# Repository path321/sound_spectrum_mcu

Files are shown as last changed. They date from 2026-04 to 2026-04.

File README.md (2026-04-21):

# Sound Analyzer

STM32-powered board for analyzing sound input from MEMS microphones, designed as an open-source, hands-on introduction to DSP on ARM Cortex-M4 processors.

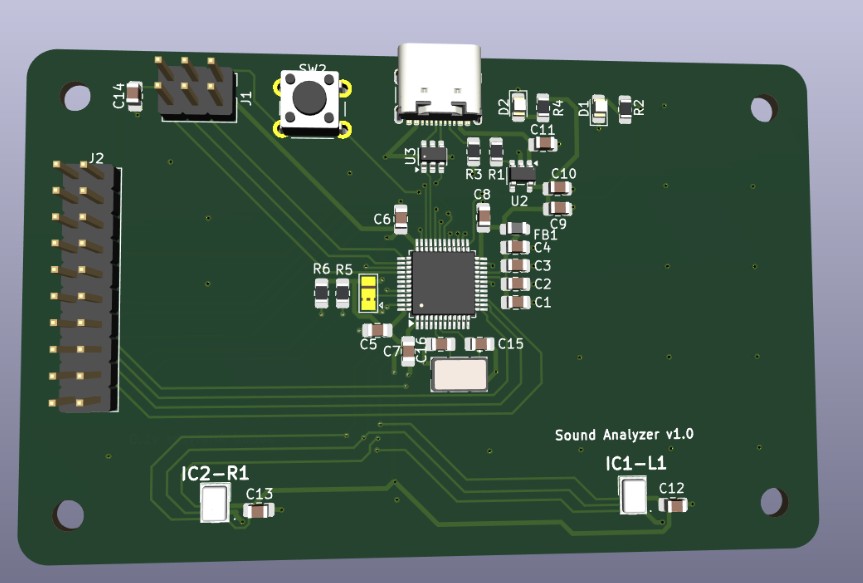
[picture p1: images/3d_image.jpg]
device_image


## Table of Contents

1. [About the Project](#about-the-project)
1. [Project Status](#project-status)
1. [Getting Started](#getting-started)
	1. [Getting the Source](#getting-the-source)
	1. [Usage](#usage)
	1. [Versioning](#versioning)
1. [How to get help](#how-to-get-help)
1. [License](#license)

## About the Project

It uses the CMSIS-DSP library to handle computationally intensive tasks, while a companion PyQt-based Python script is used for plotting frequency-domain data data from PCB to host PC. 

The goal is to demonstrate the full pipeline of audio signal acquisition and transformation, from raw time-domain data to frequency-domain analysis

The PCB intentionally exposes additional unused pins, allowing users to extend functionality and experiment beyond the core features

_1kHz sine_
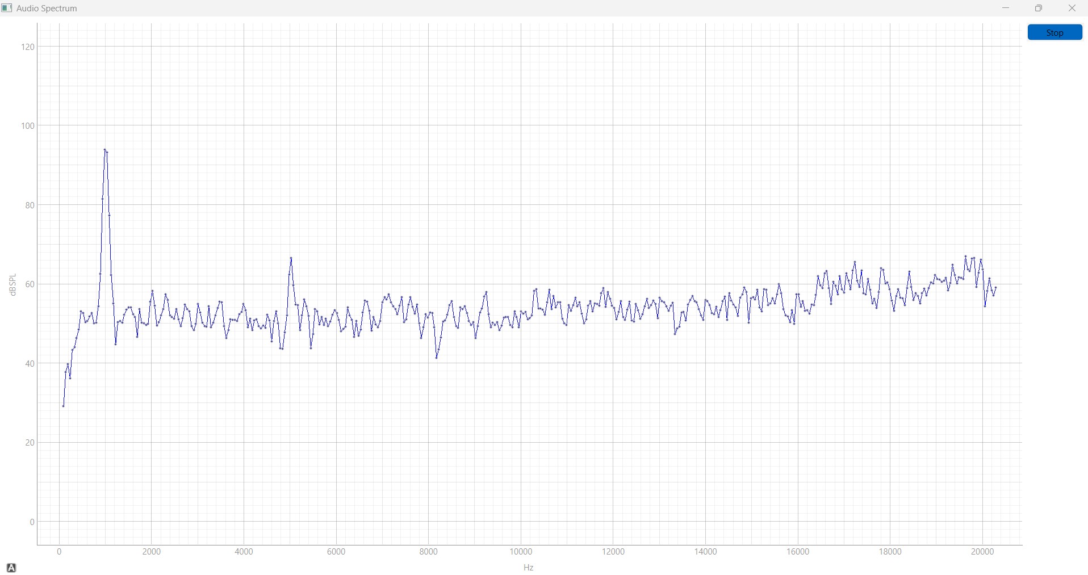
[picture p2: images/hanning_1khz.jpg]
1khz


Front                      |  Back
:-------------------------:|:-------------------------:
device_image  |  device_image

**[Back to top](#table-of-contents)**

## Project Status

In progress, working version availabe in `main` branch

Full STM32CubeIDE project is hosted here, with .elf and .bin files ready inside `code/sound_analyzer_v1/Debug` folder

As for python script, both source `plot_graph.py` and executable `plot_graph.exe` are available, with executable tested only for Windows platform

**[Back to top](#table-of-contents)**

## Getting Started

For application usage, no extra programm shall be installed , other than downloading the executable plot_graph.exe

For developer usage, STM32CubeIDE + STM32CubeMX shall be installed, as described [here](https://wiki.st.com/stm32mcu/wiki/STM32StepByStep:Step1_Tools_installation)

In addition, Python >=3.9 shall be installed from [here](https://www.python.org/downloads/), with the following Python libraries also installed :
- Numpy
- PySide6
- pyqtgraph
- Pyserial

PCB files are located on `pcb/` folder, while device files can be found on `code/sound_analyzer_v1/` and plot files on `code/plot_graph/`

### Getting the Source

This project is [hosted on GitHub](https://github.com/path321/sound_spectrum_mcu). You can clone this project directly using this command:

```
https://github.com/path321/sound_spectrum_mcu.git
```

### Usage

1) Connect the board via USB to your host PC. Make sure that no other STM32-based USB is connected to PC

2) Unzip plot_graph.zip Double click on plot_graph.exe

3) If you want to stop the live graph, check on the Button on the top right end of the GUI window

### Versioning

This project uses [Semantic Versioning](http://semver.org/). For a list of available versions, see the [repository tag list](https://github.com/path321/sound_spectrum_mcu/tags).

**[Back to top](#table-of-contents)**

## How to Get Help

Please create a new issue on

```https://github.com/path321/sound_spectrum_mcu/issues```

**[Back to top](#table-of-contents)**

## License

This project is licensed under the MIT License - see [LICENSE.md](LICENSE.md) file for details.

**[Back to top](#table-of-contents)**

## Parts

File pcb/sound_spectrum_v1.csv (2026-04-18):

Reference | Qty | Value | DNP | Exclude from BOM | Exclude from Board | Footprint | Datasheet | Manufacturer_Part_Number
C1,C3,C6,C7,C8,C12,C13,C14 | 8 | 100nF |  |  |  | Capacitor_SMD:C_0805_2012Metric_Pad1.18x1.45mm_HandSolder | ~ | 581-KGM21NR71E104KM
C2,C4,C5,C9 | 4 | 1uF |  |  |  | Capacitor_SMD:C_0805_2012Metric_Pad1.18x1.45mm_HandSolder | ~ | 80-C0805C105Z4VAC
C10,C11 | 2 | 10uF |  |  |  | Capacitor_SMD:C_0805_2012Metric_Pad1.18x1.45mm_HandSolder | ~ | 81-GRM21BR61C106KE15
C15,C16 | 2 | 33pF |  |  |  | Capacitor_SMD:C_0805_2012Metric_Pad1.18x1.45mm_HandSolder | ~ | 80-C0805C105Z4VAC
D1 | 1 | LED - Green |  |  |  | LED_SMD:LED_0805_2012Metric_Pad1.15x1.40mm_HandSolder | ~ | C171KGKT
D2 | 1 | LED - Red |  |  |  | LED_SMD:LED_0805_2012Metric_Pad1.15x1.40mm_HandSolder | ~ | CMDA5AR7D1S
FB1 | 1 | ~ |  |  |  | Inductor_SMD:L_0805_2012Metric_Pad1.05x1.20mm_HandSolder | ~ | ASMPH-0805-4R7M-T
IC1-L1,IC2-R1 | 2 | ICS-43432 |  |  |  | ICS43432 | https://product.tdk.com/system/files/dam/doc/product/sw_piezo/mic/mems-mic/data_sheet/ics-43432-data-sheet-v1.3.pdf | ICS-43432
J1 | 1 | SWD_CONN |  |  |  | Connector_PinHeader_2.54mm:PinHeader_2x03_P2.54mm_Vertical | ~ | 10129381-906004BLF
J2 | 1 | Conn_02x10_Counter_Clockwise |  |  |  | Connector_PinHeader_2.54mm:PinHeader_2x10_P2.54mm_Vertical | ~ | 77313-818-20LF
P1 | 1 | USB_C_Plug_USB2.0 |  |  |  | Connector_USB:USB_C_Receptacle_GCT_USB4105-xx-A_16P_TopMnt_Horizontal | https://www.usb.org/sites/default/files/documents/usb_type-c.zip | USB4085-GF-A
R1 | 1 | 10k |  |  |  | Resistor_SMD:R_0805_2012Metric_Pad1.20x1.40mm_HandSolder | ~ | 603-AC0805DR-0710KL
R2,R4 | 2 | 1k |  |  |  | Resistor_SMD:R_0805_2012Metric_Pad1.20x1.40mm_HandSolder | ~ | 603-AA0805FR-071KL
R3 | 1 | 5.1k |  |  |  | Resistor_SMD:R_0805_2012Metric_Pad1.20x1.40mm_HandSolder | ~ | CRCW08055K10JNEA
R5,R6 | 2 | 4.7k |  |  |  | Resistor_SMD:R_0805_2012Metric_Pad1.20x1.40mm_HandSolder | ~ | 603-RC0805FR-074K7L
SW2 | 1 | SW_DPST_x2 |  |  |  | Button_Switch_THT:SW_PUSH_6mm | ~ | TS04-66-55-BK-100-SMT-TR
U1 | 1 | STM32G473CBTx |  |  |  | Package_QFP:LQFP-48_7x7mm_P0.5mm | https://www.st.com/resource/en/datasheet/stm32g473cb.pdf | STM32G473CBT6
U2 | 1 | AP2112K-3.3 |  |  |  | Package_TO_SOT_SMD:SOT-23-5 | https://www.diodes.com/assets/Datasheets/AP2112.pdf | AP2112K-3.3TRG1
U3 | 1 | USBLC6-2SC6 |  |  |  | Package_TO_SOT_SMD:SOT-23-6 | https://www.st.com/resource/en/datasheet/usblc6-2.pdf | USBLC6-2SC6
Y1 | 1 | ABMM2-24.000MHZ-E2-T |  |  |  | ABMM2 | https://abracon.com/Resonators/ABMM2.pdf | ABMM2-24.000MHZ-E2-T

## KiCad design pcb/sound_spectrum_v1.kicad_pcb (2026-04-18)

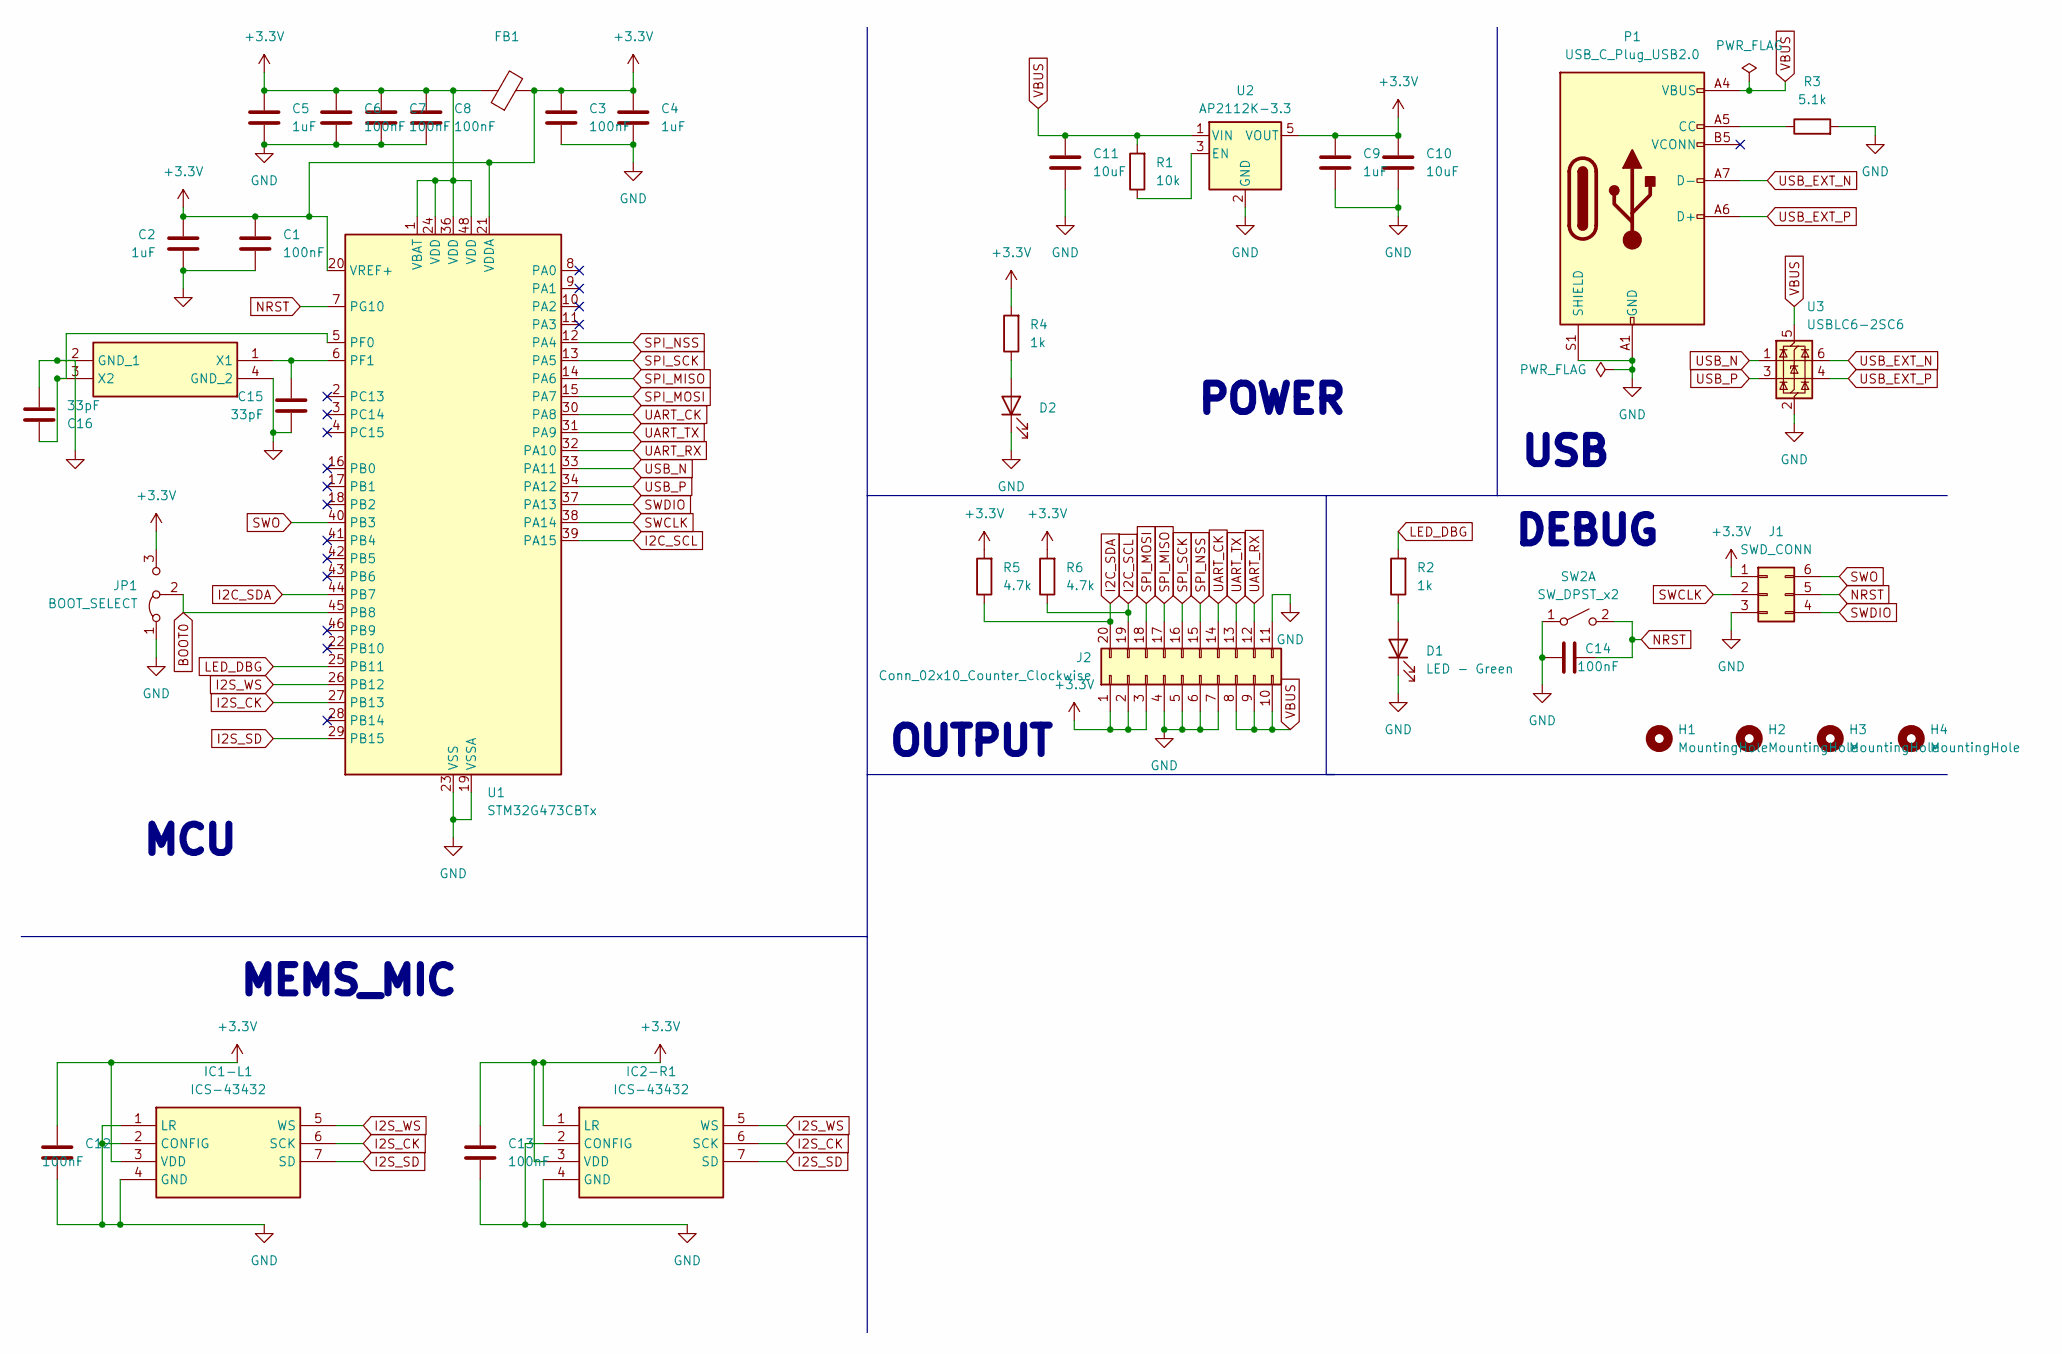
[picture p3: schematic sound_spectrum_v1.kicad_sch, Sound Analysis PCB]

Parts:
C1, C3, C6, C7, C8, C12, C13, C14: 100nF; C_0805_2012Metric_Pad1.18x1.45mm_HandSolder; Manufacturer_Part_Number 581-KGM21NR71E104KM
C2, C4, C5, C9: 1uF; C_0805_2012Metric_Pad1.18x1.45mm_HandSolder; Manufacturer_Part_Number 80-C0805C105Z4VAC
C10, C11: 10uF; C_0805_2012Metric_Pad1.18x1.45mm_HandSolder; Manufacturer_Part_Number 81-GRM21BR61C106KE15
C15, C16: 33pF; C_0805_2012Metric_Pad1.18x1.45mm_HandSolder; Manufacturer_Part_Number 80-C0805C105Z4VAC
D1: LED - Green; LED_0805_2012Metric_Pad1.15x1.40mm_HandSolder; Manufacturer_Part_Number C171KGKT
D2: LED - Red; LED_0805_2012Metric_Pad1.15x1.40mm_HandSolder; Manufacturer_Part_Number CMDA5AR7D1S
FB1: L_0805_2012Metric_Pad1.05x1.20mm_HandSolder; Manufacturer_Part_Number ASMPH-0805-4R7M-T
H1, H2, H3, H4: MountingHole; MountingHole_3.2mm_M3_DIN965
IC1-L1, IC2-R1: ICS-43432; ICS43432; Manufacturer_Part_Number ICS-43432; Mouser Part Number 410-ICS-43432
J1: SWD_CONN; PinHeader_2x03_P2.54mm_Vertical; Manufacturer_Part_Number 10129381-906004BLF
J2: Conn_02x10_Counter_Clockwise; PinHeader_2x10_P2.54mm_Vertical; Manufacturer_Part_Number 77313-818-20LF
JP1: BOOT_SELECT; SolderJumper-3_P1.3mm_Bridged2Bar12_Pad1.0x1.5mm
P1: USB_C_Plug_USB2.0; USB_C_Receptacle_GCT_USB4105-xx-A_16P_TopMnt_Horizontal; Manufacturer_Part_Number USB4085-GF-A
R1: 10k; R_0805_2012Metric_Pad1.20x1.40mm_HandSolder; Manufacturer_Part_Number 603-AC0805DR-0710KL
R2, R4: 1k; R_0805_2012Metric_Pad1.20x1.40mm_HandSolder; Manufacturer_Part_Number 603-AA0805FR-071KL
R3: 5.1k; R_0805_2012Metric_Pad1.20x1.40mm_HandSolder; Manufacturer_Part_Number CRCW08055K10JNEA
R5, R6: 4.7k; R_0805_2012Metric_Pad1.20x1.40mm_HandSolder; Manufacturer_Part_Number 603-RC0805FR-074K7L
SW2: SW_DPST_x2; SW_PUSH_6mm; Manufacturer_Part_Number TS04-66-55-BK-100-SMT-TR
U1: STM32G473CBTx; LQFP-48_7x7mm_P0.5mm; Manufacturer_Part_Number STM32G473CBT6
U2: AP2112K-3.3; SOT-23-5; Manufacturer_Part_Number AP2112K-3.3TRG1
U3: USBLC6-2SC6; SOT-23-6; Manufacturer_Part_Number USBLC6-2SC6
Y1: ABMM2-24.000MHZ-E2-T; ABMM2; Mouser Part Number 815-ABMM2-24-E2T

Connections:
+3.3V: C1.1, C2.1, C3.1, C4.1, C5.1, C6.1, C7.1, C8.1, C9.1, C10.1, C12.1, C13.1, FB1.1, FB1.2, IC1-L1.3 (VDD), IC2-R1.1 (LR), IC2-R1.3 (VDD), J1.1, J2.1, J2.2, J2.3, JP1.3 (B), R4.2, R5.2, R6.2, U1.1 (VBAT), U1.20 (VREF+), U1.21 (VDDA), U1.24 (VDD), U1.36 (VDD), U1.48 (VDD), U2.5 (VOUT)
BOOT0: JP1.2 (C), U1.45 (PB8)
GND: C1.2, C2.2, C3.2, C4.2, C5.2, C6.2, C7.2, C8.2, C9.2, C10.2, C11.2, C12.2, C13.2, C14.1, C15.2, C16.2, D1.1 (K), D2.1 (K), IC1-L1.1 (LR), IC1-L1.2 (CONFIG), IC1-L1.4 (GND), IC2-R1.2 (CONFIG), IC2-R1.4 (GND), J1.3, J2.4, J2.5, J2.6, J2.7, J2.11, JP1.1 (A), P1.A1 (GND), P1.A12 (GND), P1.B1 (GND), P1.B12 (GND), P1.S1 (SHIELD), R3.2, SW2.1 (A), U1.19 (VSSA), U1.23 (VSS), U1.35 (VSS), U1.47 (VSS), U2.2 (GND), U3.2 (GND), Y1.2 (GND_1), Y1.4 (GND_2)
I2C_SCL: J2.19, R6.1, U1.39 (PA15)
I2C_SDA: J2.20, R5.1, U1.44 (PB7)
I2S_CK: IC1-L1.6 (SCK), IC2-R1.6 (SCK), U1.27 (PB13)
I2S_SD: IC1-L1.7 (SD), IC2-R1.7 (SD), U1.29 (PB15)
I2S_WS: IC1-L1.5 (WS), IC2-R1.5 (WS), U1.26 (PB12)
LED_DBG: R2.2, U1.25 (PB11)
NRST: C14.2, J1.5, SW2.2 (B), U1.7 (PG10)
unnamed: D1.2 (A), R2.1
unnamed: D2.2 (A), R4.1
unnamed: P1.A5 (CC), R3.1
unnamed: C16.1, U1.5 (PF0), Y1.3 (X2)
unnamed: C15.1, U1.6 (PF1), Y1.1 (X1)
unnamed: R1.1, U2.3 (EN)
SPI_MISO: J2.17, U1.14 (PA6)
SPI_MOSI: J2.18, U1.15 (PA7)
SPI_NSS: J2.15, U1.12 (PA4)
SPI_SCK: J2.16, U1.13 (PA5)
SWCLK: J1.2, U1.38 (PA14)
SWDIO: J1.4, U1.37 (PA13)
SWO: J1.6, U1.40 (PB3)
UART_CK: J2.14, U1.30 (PA8)
UART_RX: J2.12, U1.32 (PA10)
UART_TX: J2.13, U1.31 (PA9)
USB_EXT_N: P1.A7 (D-), U3.6 (I/O1)
USB_EXT_P: P1.A6 (D+), U3.4 (I/O2)
USB_N: U1.33 (PA11), U3.1 (I/O1)
USB_P: U1.34 (PA12), U3.3 (I/O2)
VBUS: C11.1, J2.8, J2.9, J2.10, P1.A4 (VBUS), P1.A9 (VBUS), P1.B4 (VBUS), P1.B9 (VBUS), R1.2, U2.1 (VIN), U3.5 (VBUS)

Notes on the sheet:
MEMS_MIC
DEBUG
OUTPUT
MCU
USB
POWER

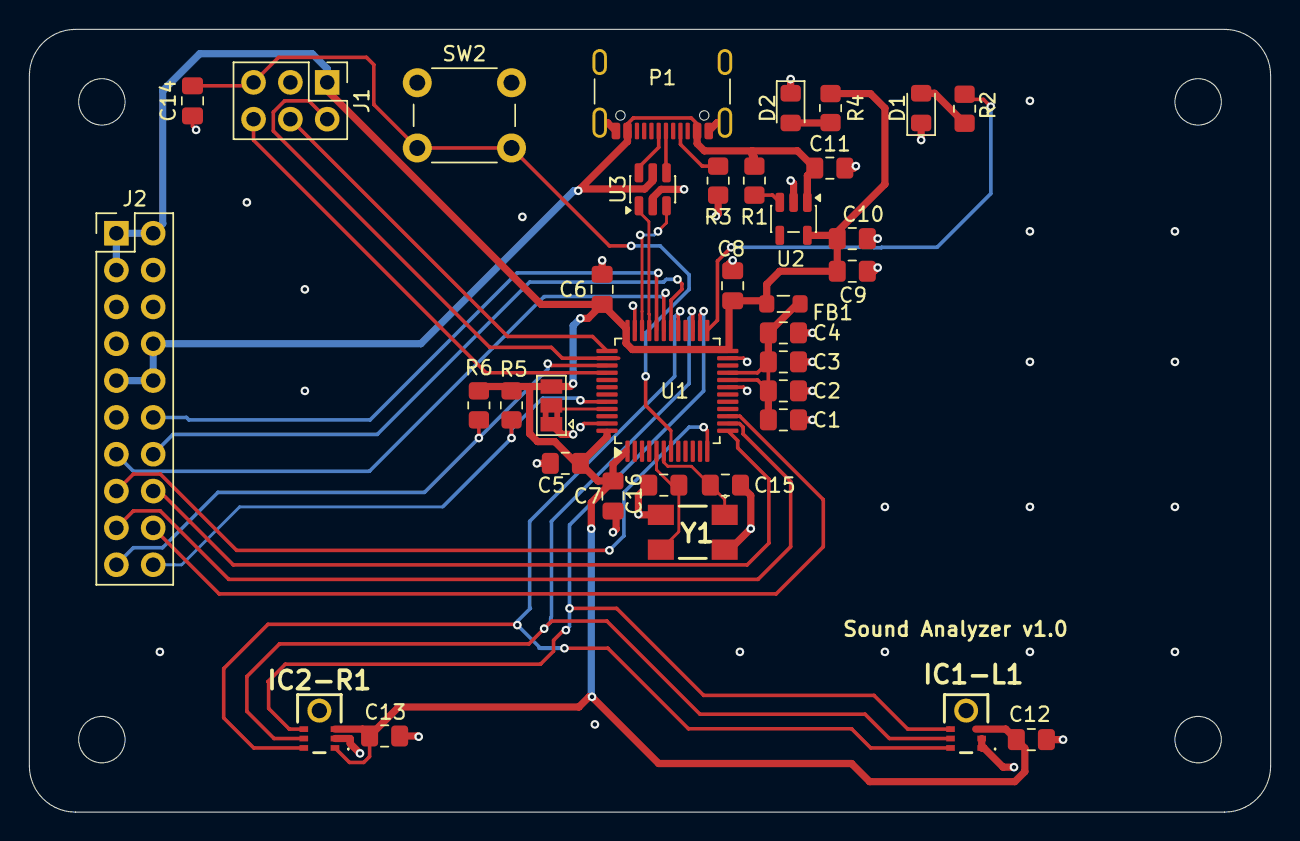
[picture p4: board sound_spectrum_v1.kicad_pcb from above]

Board: 4 copper layers, 85.6 x 54.0 mm, 40 parts (0 on the bottom side), 31 nets.

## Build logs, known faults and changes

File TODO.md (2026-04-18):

# TODO
Check the following in order to keep track of tasks

## Device FW & HW
  - [ ] Optimize USB transmit
  - [ ] Measure duration of each process
  - [ ] Display Average value

## PC SW (plotting)
 - [ ] Use Bar graphs instead of lines

## Backlog
- [ ] Redesign USB lines, as they are unstable
- [ ] Detect L/R orientation of larger frequency
- [ ] Add 'checksum' in frame / Ensure frame integrity

## Notes for next version
- Redesign USB lines, as they are unstable
- Add audio codec IC
- Use larger resistor for Green Led (too bright now)
- Use MCU with larger Flash

## Done
- [x] Demo firmware on STM32401RE-NUCLEO + ICS43434 board
- [x] Design HW board for STM32G473CBT
- [x] Plot data with Python real time-like
- [x] Show only >50Hz and <20.3kHz in X-axis
- [x] Average signal between transmit
- [X] Show error message in case device is not found
- [X] Add buttons for Run/Stop plotting
- [X] Code restructure with PySide
- [X] Detect COM port of HW board automatically via USB descriptors (need improving)

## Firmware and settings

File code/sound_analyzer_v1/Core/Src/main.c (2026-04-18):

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
/* Includes ------------------------------------------------------------------*/
#include "main.h"
#include "usb_device.h"

/* USER CODE BEGIN Includes */
#include "usbd_cdc_if.h"
#include <string.h>
#include <stdbool.h>
#include "arm_math.h"
#include "weighting.h"
#include "window.h"
/* USER CODE END Includes */

/* USER CODE BEGIN PD */
#define ARM_MATH_CM4

#define DOUBLE_BUFFER_SIZE 4096
#define HALF_DOUBLE_BUFFER_SIZE DOUBLE_BUFFER_SIZE/2
#define FFT_SIZE 1024
#define HALF_FFT_SIZE FFT_SIZE/2
#define SAMPLING_RATE 47872//~48000 , taken from CubeMX

#define USE_FLATTOP_WINDOW
//#define USE_HANNING_WINDOW
//#define USE_RECTANGULAR_WINDOW

#define USE_A_WEIGHTING
//#define USE_C_WEIGHTING

#if ((!defined(USE_FLATTOP_WINDOW))&&(!defined(USE_HANNING_WINDOW))&&(!defined(USE_RECTANGULAR_WINDOW)) || (defined(USE_HANNING_WINDOW)&&defined(USE_RECTANGULAR_WINDOW))|| (defined(USE_FLATTOP_WINDOW)&&defined(USE_RECTANGULAR_WINDOW)) || (defined(USE_FLATTOP_WINDOW)&&defined(USE_HANNING_WINDOW)))
#error "Please choose at least one between GSM,NBIOT and CATM definition"
#endif

#if defined(USE_A_WEIGHTING) && defined(USE_C_WEIGHTING)
#error "Please choose only 1 between A and C weighting"
#endif

#if (DOUBLE_BUFFER_SIZE % FFT_SIZE) != 0
#error "Input buffer size shall be integer multiple of FFT size"
#endif
/* USER CODE END PD */

I2S_HandleTypeDef hi2s2;
DMA_HandleTypeDef hdma_spi2_rx;

/* USER CODE BEGIN PV */
static uint16_t mic_data[DOUBLE_BUFFER_SIZE];
static volatile uint16_t *buf_ptr = &mic_data[0]; //pointer to each half of buffer

static volatile bool data_ready_flag = false;
static volatile bool buffer_filled = false;
static volatile bool fft_done = false;
/* USER CODE END PV */

void SystemClock_Config(void);
static void MX_GPIO_Init(void);
static void MX_DMA_Init(void);
static void MX_I2S2_Init(void);
/* USER CODE BEGIN PFP */

static void process_input_data(float32_t*);
static void compute_frequencies(arm_rfft_fast_instance_f32*,float32_t*,float32_t*);
static void scale_frequencies(float32_t* , float32_t* );
static void show_values(float32_t*, size_t );
/* USER CODE END PFP */

/**
 * @brief  The application entry point.
 * @retval int
 */
int main(void) {

	/* MCU Configuration--------------------------------------------------------*/

	/* Reset of all peripherals, Initializes the Flash interface and the Systick. */
	HAL_Init();

	/* Configure the system clock */
	SystemClock_Config();

	/* USER CODE BEGIN SysInit */
#if 0
  //Enable cycle counter for measuring time duration
  CoreDebug->DEMCR |= CoreDebug_DEMCR_TRCENA_Msk;
  DWT->CYCCNT = 0;
  DWT->CTRL |= DWT_CTRL_CYCCNTENA_Msk;
  volatile uint32_t t1;
  volatile uint32_t t2;
  volatile uint32_t diff;
  const uint32_t sys_clock_freq = HAL_RCC_GetSysClockFreq();
#endif
	/* USER CODE END SysInit */

	/* Initialize all configured peripherals */
	MX_GPIO_Init();
	MX_DMA_Init();
	MX_I2S2_Init();
	MX_USB_Device_Init();
	/* USER CODE BEGIN 2 */
	arm_rfft_fast_instance_f32 hfft;
	//const float32_t frequency_resolution = (float32_t) SAMPLING_RATE / (float32_t) FFT_SIZE;

	float32_t input_td[FFT_SIZE] = { 0 };
	float32_t fft_mag[HALF_FFT_SIZE] = { 0 };
	float32_t output_db[HALF_FFT_SIZE] = { 0 };

	uint32_t last_send = 0;
	uint32_t refresh_time = 10; //ms

	HAL_GPIO_WritePin(LED_DBG_GPIO_Port, LED_DBG_Pin, GPIO_PIN_SET);
	HAL_Delay(500);
	HAL_GPIO_WritePin(LED_DBG_GPIO_Port, LED_DBG_Pin, GPIO_PIN_RESET);
	HAL_Delay(500);

	//arm_rfft_fast_init_f32(&hfft, FFT_SIZE);
#if (FFT_SIZE != 1024)
#error "Please use respective arm_rfft_fast_init_XXX_f32() function"
#else
	arm_rfft_fast_init_1024_f32(&hfft); //Use specific size for less build code size
#endif

	//Start reading from microphones
	if (HAL_I2S_Receive_DMA(&hi2s2, mic_data, HALF_DOUBLE_BUFFER_SIZE)
			!= HAL_OK) {
		Error_Handler();
	}

	//Successful initilization
	HAL_GPIO_WritePin(LED_DBG_GPIO_Port, LED_DBG_Pin, GPIO_PIN_SET);

	/* USER CODE END 2 */

	/* Infinite loop */
	/* USER CODE BEGIN WHILE */
	while (1) {
		if (data_ready_flag) {
			data_ready_flag = false;
			process_input_data(input_td);
		}

		if (buffer_filled) {
			buffer_filled = false;
			compute_frequencies(&hfft, input_td,fft_mag);
		}

		if (((HAL_GetTick() - last_send) >= refresh_time) && fft_done && tx_complete) {
			last_send = HAL_GetTick();
			fft_done = false;
			tx_complete = false;
			scale_frequencies(fft_mag, output_db);
			show_values(output_db, HALF_FFT_SIZE);
		}
		/* USER CODE END WHILE */

		/* USER CODE BEGIN 3 */
	}
	/* USER CODE END 3 */
}

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
/* USER CODE BEGIN 4 */
/**
 * @brief Reform incoming data from stereo 24-bit integer to mono float, to prepare them for FFT
 * param[out] input_td Array to store time-domain data from microphone
 */
static void process_input_data(float32_t* mic_data) {

	static int index = 0;
	uint16_t input_data[HALF_DOUBLE_BUFFER_SIZE];
	static const float32_t full_range = 0x7fffff; //2^23 - 1

	//Copy data to avoid corruption
	memcpy(input_data, (uint16_t*) buf_ptr, sizeof(input_data));

	for (size_t i = 0; i < HALF_DOUBLE_BUFFER_SIZE; i = i + 4) {
		// Get data from I2S for each channel
		int32_t left_channel = (((int32_t) input_data[i] << 16)
				| input_data[i + 1]);
		int32_t right_channel = (((int32_t) input_data[i + 2] << 16)
				| input_data[i + 3]);

		//Keep only 24bits and take care of sign
		left_channel &= 0xFFFFFF;
		right_channel &= 0xFFFFFF;
		if (left_channel & 0x800000) {
			left_channel |= ~0xFFFFFF;
		}
		if (right_channel & 0x800000) {
			right_channel |= ~0xFFFFFF;
		}

		//Stereo to mono ( (L+R)/2 ) & normalize to Full Scale [-1.0,1.0]
		float32_t mono = ((float32_t) (left_channel + right_channel) / 2.0)
				/ full_range;

		mic_data[index] = mono;
		index++;
	}

	if (index == FFT_SIZE) {
		buffer_filled = true;
		index = 0; // set for next iteration
	}

}

/**
 * @brief Apply Fast Fourier Transformation to incoming data and compute spectral content of signal
 * @param[in] hfft FFT handler
 * @param[in] input_td Time-domain data from microphone
 * @param[out] out_freq dBFS signal values in frequency
 */
static void compute_frequencies(arm_rfft_fast_instance_f32* hfft,float32_t* input_td,float32_t* output_freq) {

	//Intermediate buffers used as input/output between actions
	float32_t input_td_windowed[FFT_SIZE] = { 0 };
	float32_t fft_out[FFT_SIZE] = { 0 };
	float32_t mag_now[HALF_FFT_SIZE] = { 0 };
	float32_t temp[HALF_FFT_SIZE] = { 0 };
	static const uint8_t ifft_flag = 0;

	//Weight for current values in weighted moving average
	static const float32_t alpha = 0.5;

	//Window functions
#if defined(USE_HANNING_WINDOW)
	static float32_t const* window = hanning;
	static float32_t sum_of_window = sum_hanning;
#elif defined(USE_FLATTOP_WINDOW)
	static float32_t const* window = flattop;
	static const float32_t sum_of_window = sum_flattop;
#else
	static float32_t const* window = rectangular;
	static float32_t sum_of_window = sum_rectangular;
#endif

	//Remove DC Offset
	float32_t mean;
	arm_mean_f32(input_td, FFT_SIZE, &mean);
	arm_offset_f32(input_td, -mean, temp, FFT_SIZE);

	//Apply windowing to time data
	arm_mult_f32(temp, window, input_td_windowed, FFT_SIZE);

	//Apply (Real) Fast FFT to input array
	arm_rfft_fast_f32(hfft, input_td_windowed, fft_out, ifft_flag);

	//Compute magnitude from complex FFT array
	arm_cmplx_mag_f32(fft_out, temp, HALF_FFT_SIZE);

	//Normalize magnitude, for one-sided FFT and windowing
	arm_scale_f32(temp, 2.0/sum_of_window , mag_now, HALF_FFT_SIZE);

	//Average spectrum values
	for (int i = 0; i < HALF_FFT_SIZE; i++) {
		output_freq[i] = mag_now[i] * alpha + output_freq[i] * (1 - alpha);
	}

	fft_done = true;
}

/**
 *@brief Scale magnitude to a real-world Decibel value
 *@param[in] input_freq Result of FFT , in magnitude
 *@param[out] output_db data after transpose to decibel scale
 */
static void scale_frequencies(float32_t* input_freq, float32_t* output_db){

	float32_t dbfs[HALF_FFT_SIZE] = {0};
	float32_t temp[HALF_FFT_SIZE] = { 0 };

	//Compute dBFS from magnitude - break the computation to steps with pre-computed values for code optimization
	//dBFS = 20*log10(mag) = 20*(ln(mag*)/ln(10))
	arm_vlog_f32(input_freq, temp, HALF_FFT_SIZE); // = ln(mag)
	arm_scale_f32(temp, 8.6858896380, dbfs, HALF_FFT_SIZE); // = (20/ln(10))*ln(mag) = 8.685889638*ln(mag)

	//Offset to dBSPL, based on calibration from mic specification
#if defined(USE_A_WEIGHTING)
	//Apply A-Weighting to dBSPL
	arm_offset_f32(dbfs, 120, temp, HALF_FFT_SIZE);
	arm_add_f32(temp,a_weighting_db,output_db,HALF_FFT_SIZE);
#elif defined(USE_C_WEIGHTING)
	//Apply C-Weighting to dBSPL
	arm_offset_f32(dbfs, 120, temp, HALF_FFT_SIZE);
	arm_add_f32(temp,c_weighting_db,output_db,HALF_FFT_SIZE);
#else
	arm_offset_f32(dbfs, 120, output_db, HALF_FFT_SIZE);
#endif
}


/**
 * @brief Display the results of the frequency computation
 * @param[in] data_out Output data to send to host
 */
static void show_values(float32_t* data_out, size_t data_out_sz) {

	char str_to_send[8192] = { 0 }; // arbitary large size
	int len = 0;

	// Group data to format '[I0.D0, I1.D1, ... IXX,DXX]'
	len += snprintf(str_to_send + len, sizeof(str_to_send) - len, "[");
	for (int i = 0; i < data_out_sz; i++) {
		len += snprintf(str_to_send + len, sizeof(str_to_send) - len, "%.1f,",
				data_out[i]);
	}
	snprintf(str_to_send + len - 1, sizeof(str_to_send) - len, "]\n");

	//Send them to host PC via USB
	CDC_Transmit_FS((uint8_t*) str_to_send, strlen(str_to_send));
}

void HAL_I2S_RxHalfCpltCallback(I2S_HandleTypeDef *hi2s) {
	// Choose first half of double buffer
	buf_ptr = &mic_data[0];

	data_ready_flag = true;
}

void HAL_I2S_RxCpltCallback(I2S_HandleTypeDef *hi2s) {
	// Choose second half of double buffer
	buf_ptr = &mic_data[HALF_DOUBLE_BUFFER_SIZE];

	data_ready_flag = true;
}
/* USER CODE END 4 */
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


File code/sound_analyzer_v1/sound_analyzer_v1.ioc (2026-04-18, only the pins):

Mcu.UserName=STM32G473CBTx
PA11.Signal=USB_DM
PA12.Signal=USB_DP
PA13.Signal=SYS_JTMS-SWDIO
PA14.Signal=SYS_JTCK-SWCLK
PB11.GPIO_Label=LED_DBG
PB11.Signal=GPIO_Output
PB12.Signal=I2S2_WS
PB13.Signal=I2S2_CK
PB15.Signal=I2S2_SD
PF0-OSC_IN.Signal=RCC_OSC_IN
PF1-OSC_OUT.Signal=RCC_OSC_OUT

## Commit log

2026-02-21 BREAKING CHANGE: change of mcu -> going to f401re, as well as mic -> going to ics43434 ,not working, in progress
    [main.c]
2026-03-08 fix: better handling of 24-bit data, in progress
    [main.c]
2026-03-17 feat: add first version of PCB, in progress
    feat: add first version of python script for bar graph, in progress
    chore: restructure project
    [sound_spectrum_v1.kicad_pcb, sound_spectrum_v1.kicad_sch]
2026-03-17 chore: add hanning window as a fixed array
    feat: output .bin file
    [main.c]
2026-03-18 feat: form pcb board as credit card-sized
    feat: add esd protection ic to USB singals
    fix: bug with nrst button
    fix: bug with microphone connection in schematic
    chore: added custom rules for board in jlcpcb
    [sound_spectrum_v1.kicad_pcb, sound_spectrum_v1.kicad_sch]
2026-03-18 chore: further tracing
    [sound_spectrum_v1.kicad_pcb, sound_spectrum_v1.kicad_sch]
2026-03-18 fix: replace ics-43434 with ics-43432 due to part shortage
    feat: make connections to all parts
    [sound_spectrum_v1.kicad_pcb, sound_spectrum_v1.kicad_sch]
2026-03-18 chore: move traces around
    [sound_spectrum_v1.kicad_pcb]
2026-03-19 feat: add HSE clock
    feat: update schematic
    chore: create gerber files
    [sound_spectrum_v1-B_Cu.gbr, sound_spectrum_v1-B_Mask.gbr, sound_spectrum_v1-B_Paste.gbr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]
2026-03-19 chore: generated cpl file
    fix: errors in schematic
    [sound_spectrum_v1.kicad_pcb, sound_spectrum_v1.kicad_sch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]
2026-03-19 chore: correct silkscreen
    [sound_spectrum_v1.kicad_pcb]
2026-03-21 feat: add mounting holes
    chore: change usb c receptor
    chore: align microphones
    [sound_spectrum_v1.kicad_pcb, sound_spectrum_v1.kicad_sch, sound_spectrum_v1_bom_jlc.csv]
2026-03-21 chore: minor rerouting
    [sound_spectrum_v1.kicad_pcb]
2026-03-21 chore: add extra led
    chore: minor changes
    [sound_spectrum_v1-B_Cu.gbr, sound_spectrum_v1-B_Mask.gbr, sound_spectrum_v1-B_Paste.gbr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]
2026-03-21 chore: add text in schematic
    [sound_spectrum_v1.kicad_sch]
2026-04-11 feat: normalize output bins to generate power spectrum
    feat: correct handling of stereo signal
    feat: use specific function for FFT with N -> reduce ~50% output code size
    feat: add hanning window as external file, avoid computing
    feat: change color of plot
    feat: add button for Run/Stop plot, need improving
    chore: renaming of functions for better conceptuality
    chore: code cleanup in mcu code
    chore: update TODO
    [main.c, sound_analyzer_v1.ioc]
2026-04-12 chore: code formatting
    chore: add #error guards for specific #define's
    [main.c]
2026-04-12 fix: bug with memcpy operation
    [main.c]
2026-04-12 feat: re-write plot python script, to include PySide6, cleaner code format, interactive button for Run/Stop and symbol for each data point
2026-04-14 feat: remove DC offset before fft & compute dBFS as final result
    feat: check flag for usb transmit completion
    fix: normalize time-domain data to full-scale [-1,1]
    fix: better handling of 24bit-to-32bit format
    fix: more detailed hanning window array
    fix: use N=1024 instead of 2048 -> more stable operation
    feat: add axis labels in plot
    chore: restructure function parameters
    [main.c, sound_analyzer_v1.ioc]
2026-04-16 feat: try a-weighting correction
    [main.c]
2026-04-18 feat: add flattop & rectangular window as options
    feat: add flexible normalization factor, depending on selected window
    feat: add led flashing pattern in error handler
    chore: change the range of y axis to conform to dbspl in plot_graph
    chore: add another function for translating freq magnitude values to dB
    [main.c]
2026-04-21 chore: updated readme, added images
    chore: created nuitka .exe , in progress
    [CET-C1.csv, CET-C1s.csv, CET-C2.csv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]
2026-04-21 chore: update readme
    chore: updated .exe for plotting
    [CET-C1.csv, CET-C1s.csv, CET-C2.csv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]

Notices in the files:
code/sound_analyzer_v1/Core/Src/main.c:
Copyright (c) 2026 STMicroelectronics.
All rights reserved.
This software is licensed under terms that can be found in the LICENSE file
